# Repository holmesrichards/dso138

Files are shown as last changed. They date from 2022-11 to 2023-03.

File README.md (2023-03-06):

# DSO138 Oscilloscope

This is the JYE Tech DSO138 Oscilloscope put behind a 10 cm wide Kosmo format panel. 

Slide switches, tactile buttons, and trigger indicator LED are mounted to an auxiliary PCB mounted behind the panel. Also on this board are a Eurorack style 10-pin power header with 10 µF caps and power reversal diodes, and a 9 volt regulator and TL072 op amp with associated passive components.

A BNC jack and a 1/4" phone input jack are mounted on the front panel. A toggle switch selects whether the scope input is connected to the BNC or to the 1/4" jack signal after being buffered with the TL072. The latter signal, buffered, also goes to a second 1/4" panel mounted jack, so the signal can be passed on to another module.

Also on the front panel is another toggle switch, controlling the 9 V power. (It's good to power off the scope when not in use, for at least three reasons: the scope draws about 130 mA current on the +12 V rail, it probably puts out some digital noise you don't want getting into your synth sound, and leaving it powered off when not in use will help extend the life of the display.)

Connections to and from each slide switch are sent to the DSO138 switch footprints via an 8-conductor ribbon cable. A fourth ribbon cable connects the tactile buttons, both sides of the LED, and the input signal to the appropriate pads on the main board. Two more wires carry 9 V and ground to that board, which is mounted perpendicular to the front panel. I used a 3D printed carrier and long spacers to attach it.

The display PCB is mounted to the front panel and is connected to the main PCB via a 40 conductor ribbon cable.

## Current draw
130 mA +12 V, 10 mA -12 V

## Photos

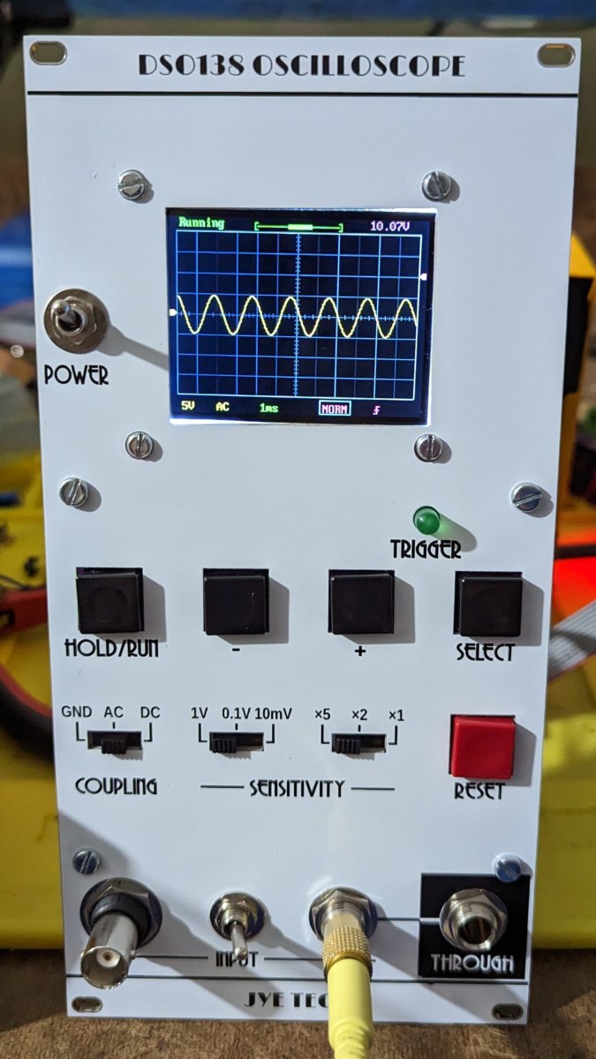
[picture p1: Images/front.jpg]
front


## Documentation

* [Schematic (auxiliary board)](Docs/dso138.pdf)
* PCB layout: [front](Docs/dso138_layout_front.pdf), [back](Docs/dso138_layout_back.pdf)
* [BOM](Docs/dso138_bom.md)
* [Build notes](Docs/build.md)

## GitHub repository

* [https://github.com/holmesrichards/dso138](https://github.com/holmesrichards/dso138)

## Submodules

This repo uses submodules aoKicad and Kosmo_panel, which provide needed libaries for KiCad. To clone:

```
git clone git@github.com:holmesrichards/dso138.git
git submodule init
git submodule update
```

Alternatively do

```
git clone --recurse-submodules git@github.com:holmesrichards/dso138.git
```

Or if you download the repository as a zip file, you must also click on the "aoKicad" and "Kosmo\_panel" links on the GitHub page (they'll be in the Libraries folder and will have "@ something" after them) and download them as separate zip files which you can unzip into this repo's aoKicad and Kosmo\_panel directories (in the Libraries folder).

If desired, copy the files from aoKicad and Kosmo\_panel to wherever you prefer. 

Then in KiCad, go into Edit Symbols and add symbol libraries 

```
aoKicad/AO_symbols
Kosmo_panel/Kosmo
```
and go into Edit Footprints and add footprint libraries 
```
aoKicad/AO_tht
Kosmo_panel/Kosmo_panel.
```

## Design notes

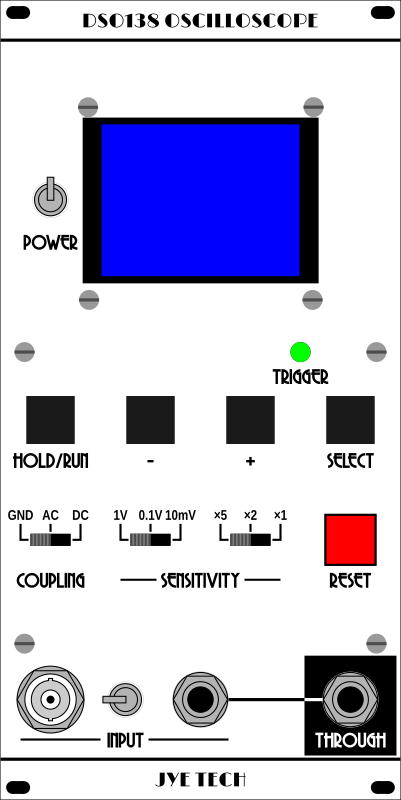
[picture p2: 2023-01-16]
Images/dso138_panel.png

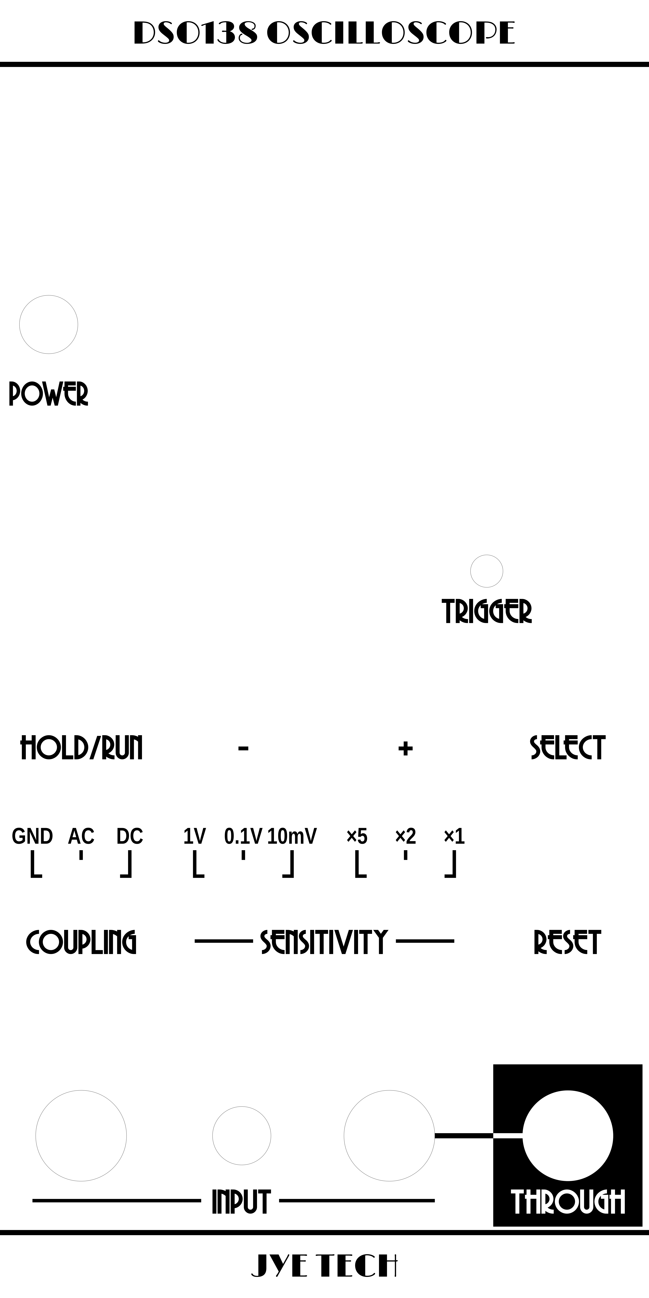
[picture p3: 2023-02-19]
Images/dso138_panel_art.png

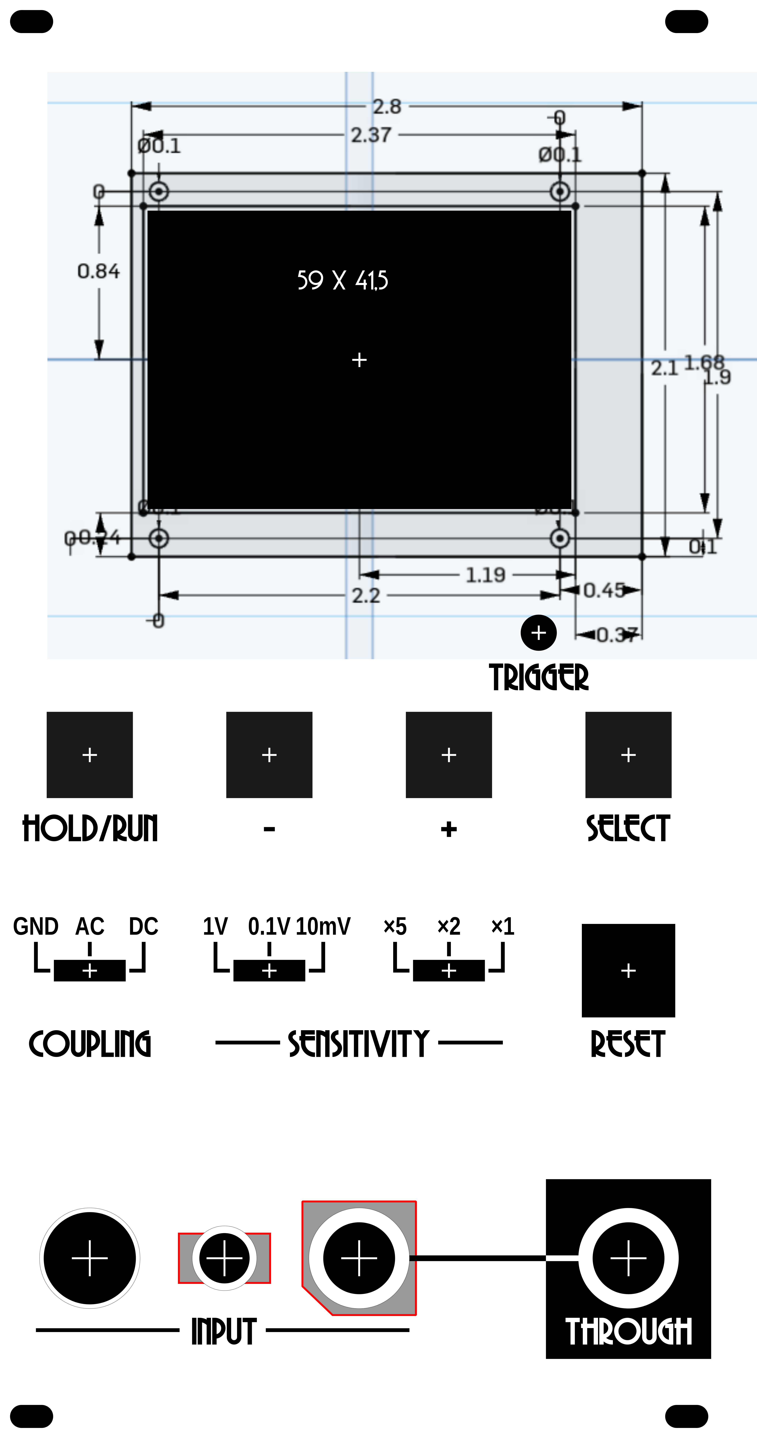
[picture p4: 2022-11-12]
Images/dso138_behind.png

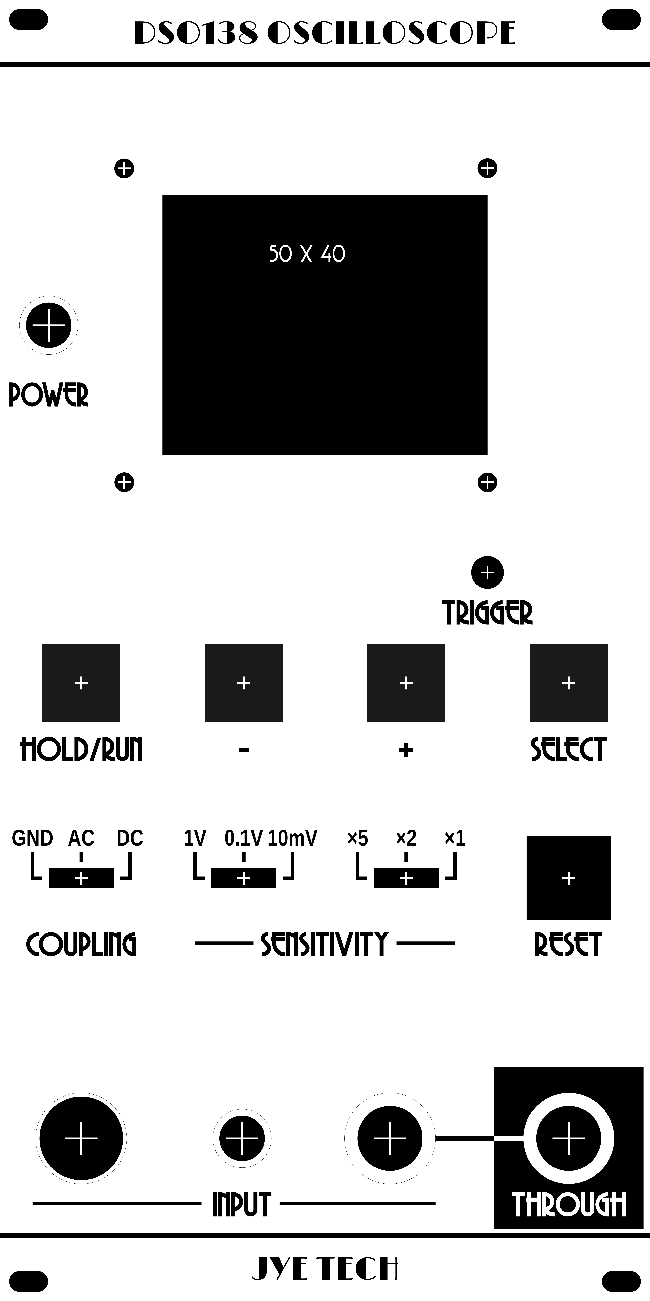
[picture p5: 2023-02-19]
Images/dso138_panel_holes.png

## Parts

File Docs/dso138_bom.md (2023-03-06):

# dso138.kicad_sch BOM

Sun 05 Mar 2023 09:16:09 PM EST

Generated from schematic by Eeschema 7.0.0-da2b9df05c~171~ubuntu22.04.1

**Component Count:** 101

| Refs | Qty | Component | Description | Manufacturer | Part | Vendor | SKU |
| ----- | --- | ---- | --- | ---- | ---- | ---- | ---- |
| C1, C2 | 2 | 10uF | Electrolytic capacitor, 2.5 mm pitch |  |  | Tayda | A-4349 |
| C3, C4, C6 | 3 | 100nF | Ceramic capacitor, 2.5 mm pitch |  |  | Tayda | A-553 |
| C5 | 1 | 330nF | Electrolytic capacitor, 2.5 mm pitch |  |  | Tayda | A-319 |
| D1, D2 | 2 | 1N5817 | Schottky Barrier Rectifier Diode, DO-41 |  |  | Tayda | A-159 |
| D3 | 1 | LED_green | Light emitting diode |  |  | Tayda | A-1553 |
| J1 | 1 | DIP-8 | 8 pin DIP socket |  |  | Tayda | A-001 |
| J2–5, J15 | 5 | Conn_01x02 | Micro JST XH 2.54mm connector with 10 cm wires |  |  | eBay |  |
| J6–9, J14 | 5 | Conn_01x02 | Micro JST XH 2.54mm header |  |  | eBay |  |
| J10–13 | 4 | Conn_02x04_Odd_Even | 2x4 pin shrouded pin header, 2.54 mm pitch |  |  | Tayda | A-2948 |
| J16–19 | 4 | Conn_02x04_Odd_Even | 2x4 pin IDC connector, 2.54 mm pitch |  |  | Tayda | A-3346 |
| J20 | 1 | Synth_power_2x5 | 2x5 pin shrouded pin header, 2.54 mm pitch |  |  | Tayda | A-2939 |
| J21, J22 | 2 | AudioJack2 | Audio Jack, 2 Poles (Mono / TS) |  |  | Tayda | A-1121 |
| J23 | 1 | Conn_Coaxial_BNC | BNC jack, panel mount | Molex | 0731315003 | Digi-Key | WM5379-ND |
| R1, R2 | 2 | 100k | Resistor |  |  | Tayda |  |
| R3, R4 | 2 | 10k | Resistor |  |  | Tayda |  |
| R5 | 1 | 1k | Resistor |  |  | Tayda |  |
| SW1–3 | 3 | SW_DP3T | DP3T slide switch | C&K | OS203012MU5QP1‎ | Digi-Key | CKN9554-ND |
| SW4–8 | 5 | SW_Push | Tactile push button | E-Switch | TL1100F160Q | Digi-Key | EG1821-ND |
| SW9 | 1 | SW_SPST | SPST toggle switch |  |  | Tayda | A-3186 (SPDT, use as SPST) |
| SW10 | 1 | SW_SPDT | SPDT toggle switch |  |  | Tayda | A-3186 |
| U1 | 1 | TL072 | Dual operational amplifier, DIP-8 |  |  | Tayda | A-037 |
| U2 | 1 | LM7809_TO220 | Positive 1A 35V Linear Regulator, Fixed Output 9V, TO-220 |  |  | Tayda | A-1597 |
| W1–4 | 4 | 8 conductor ribbon cable ~ 20 cm | Ribbon cable |  |  | Tayda | A-4935 |
| W5 | 1 | 40 conductor ribbon cable assembly with connectors (1 male, 1 female) | Ribbon cable |  |  | Digi-Key | 1528-4823-ND |
| ZKN1 | 1 | Switch cap | Tactile switch cap, red | E-Switch | 4JRED | Digi-Key | EG1078-ND |
| ZKN2–5 | 4 | Switch cap | Tactile switch cap, black | E-Switch | 4JBLK | Digi-Key | EG1080-ND |
| ZNU1–5 | 5 | M3 nut | nut |  |  |  |  |
| ZNU6–9 | 4 | M2.5 nut | nut |  |  |  |  |
| ZSC1–3, ZSC12–19 | 11 | Μ3 screw 6 mm | screw |  |  |  |  |
| ZSC4–7 | 4 | Μ3 screw 12 mm | screw |  |  |  |  |
| ZSC8–11 | 4 | M2.5 screw 12 mm | screw |  |  |  |  |
| ZSP1–4 | 4 | M3 spacer FF 5 mm | spacer |  |  |  |  |
| ZSP5–8 | 4 | M2.5 spacer FF 5 mm | spacer |  |  |  |  |
| ZSP9–12 | 4 | M3 spacer FF 10 mm | spacer |  |  |  |  |
| ZSP13, ZSP14 | 2 | M3 spacer FF 30 mm | spacer |  |  |  |  |

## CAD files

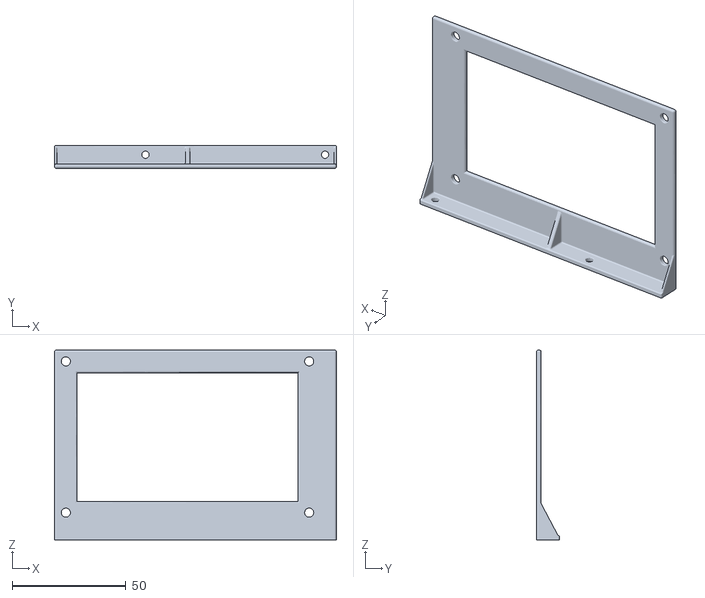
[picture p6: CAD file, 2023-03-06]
3D prints/dso138_bracket.stl
124.0 x 10.0 x 83.5

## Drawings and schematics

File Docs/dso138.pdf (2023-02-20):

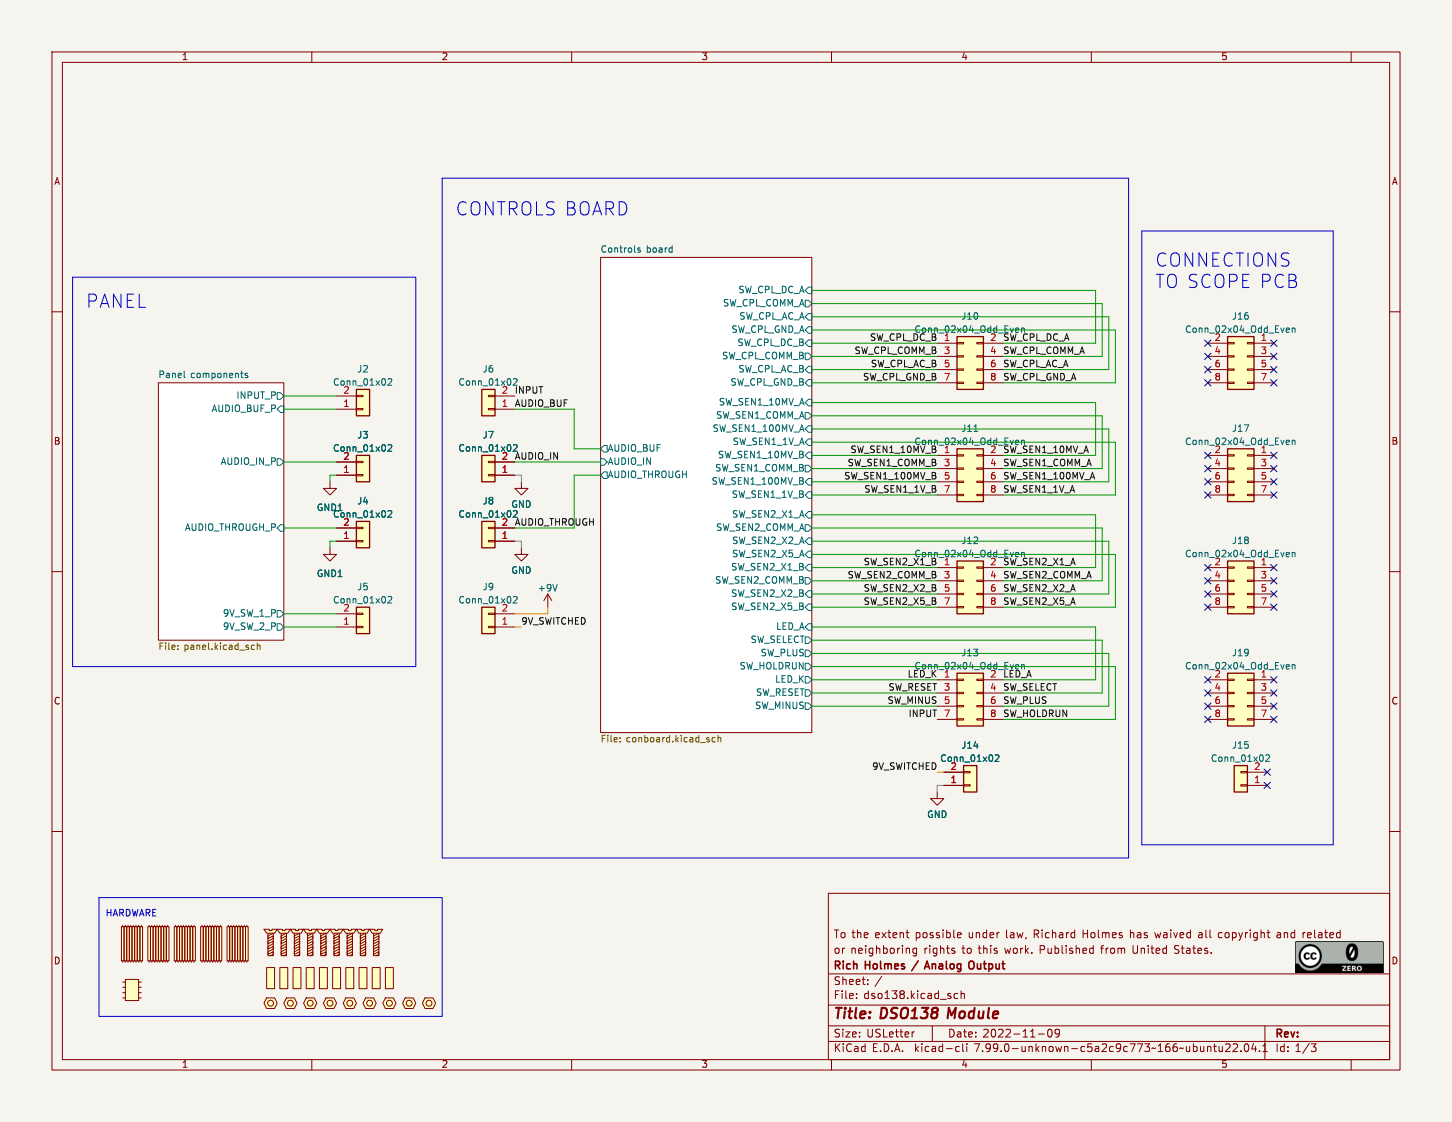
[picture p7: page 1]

SW_MINUS Controls board File: conboard.kicad_sch AUDIO_BUF_P

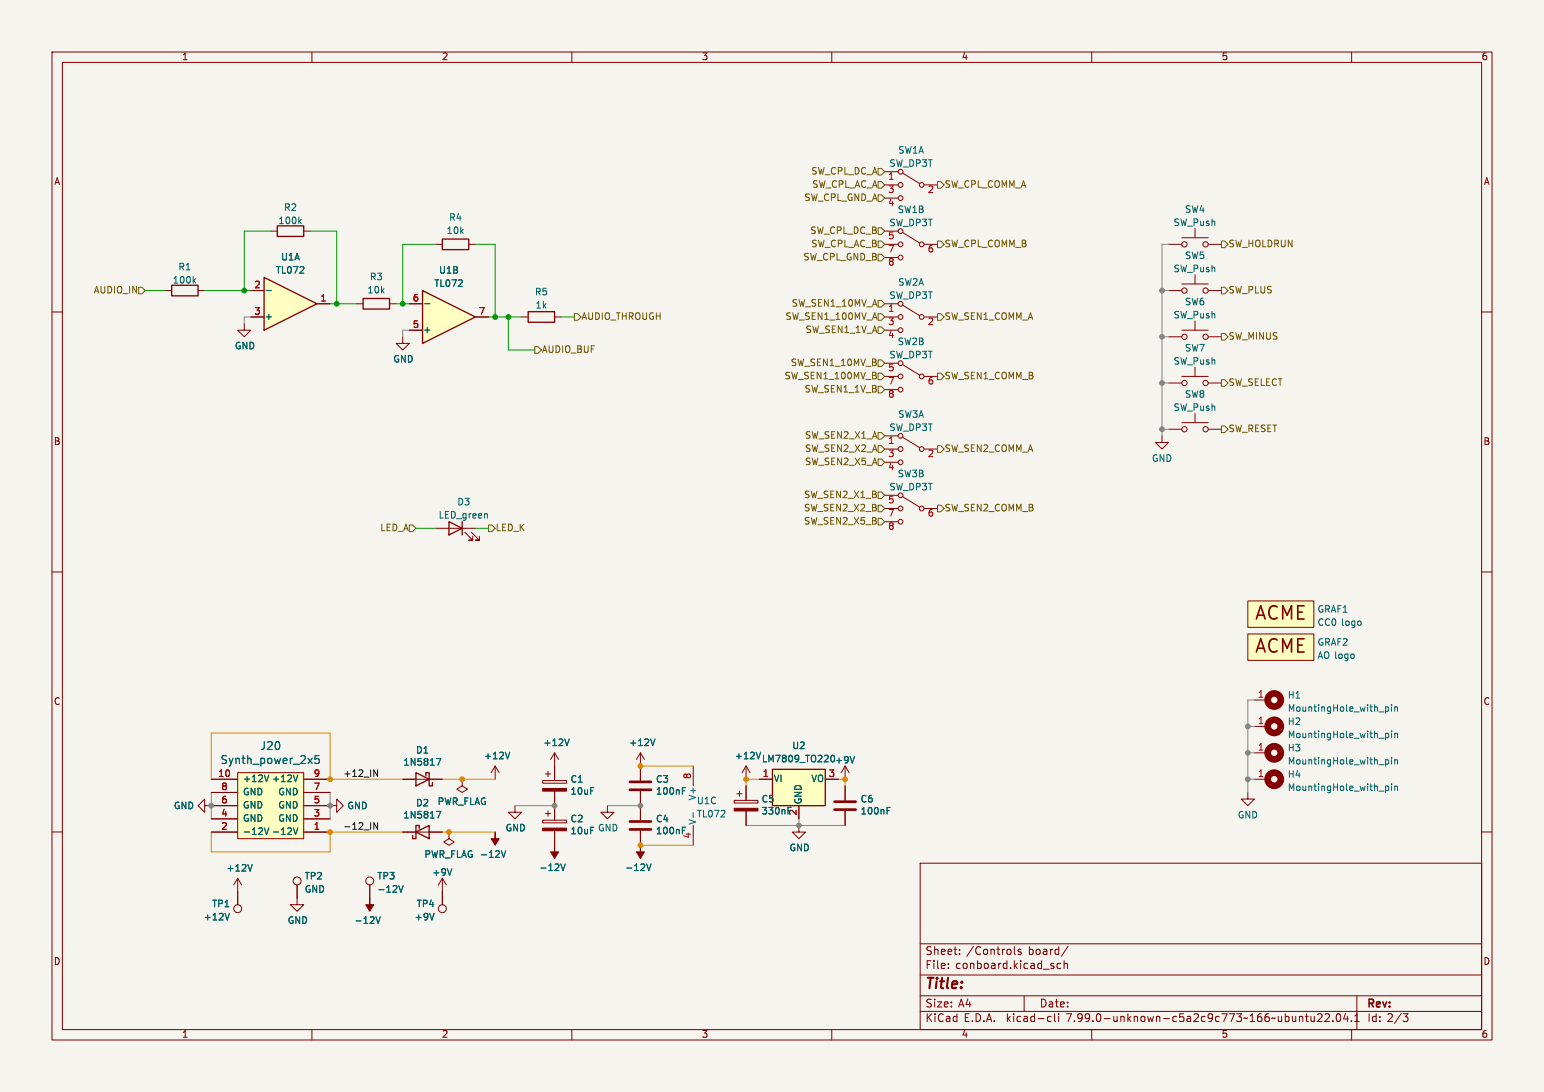
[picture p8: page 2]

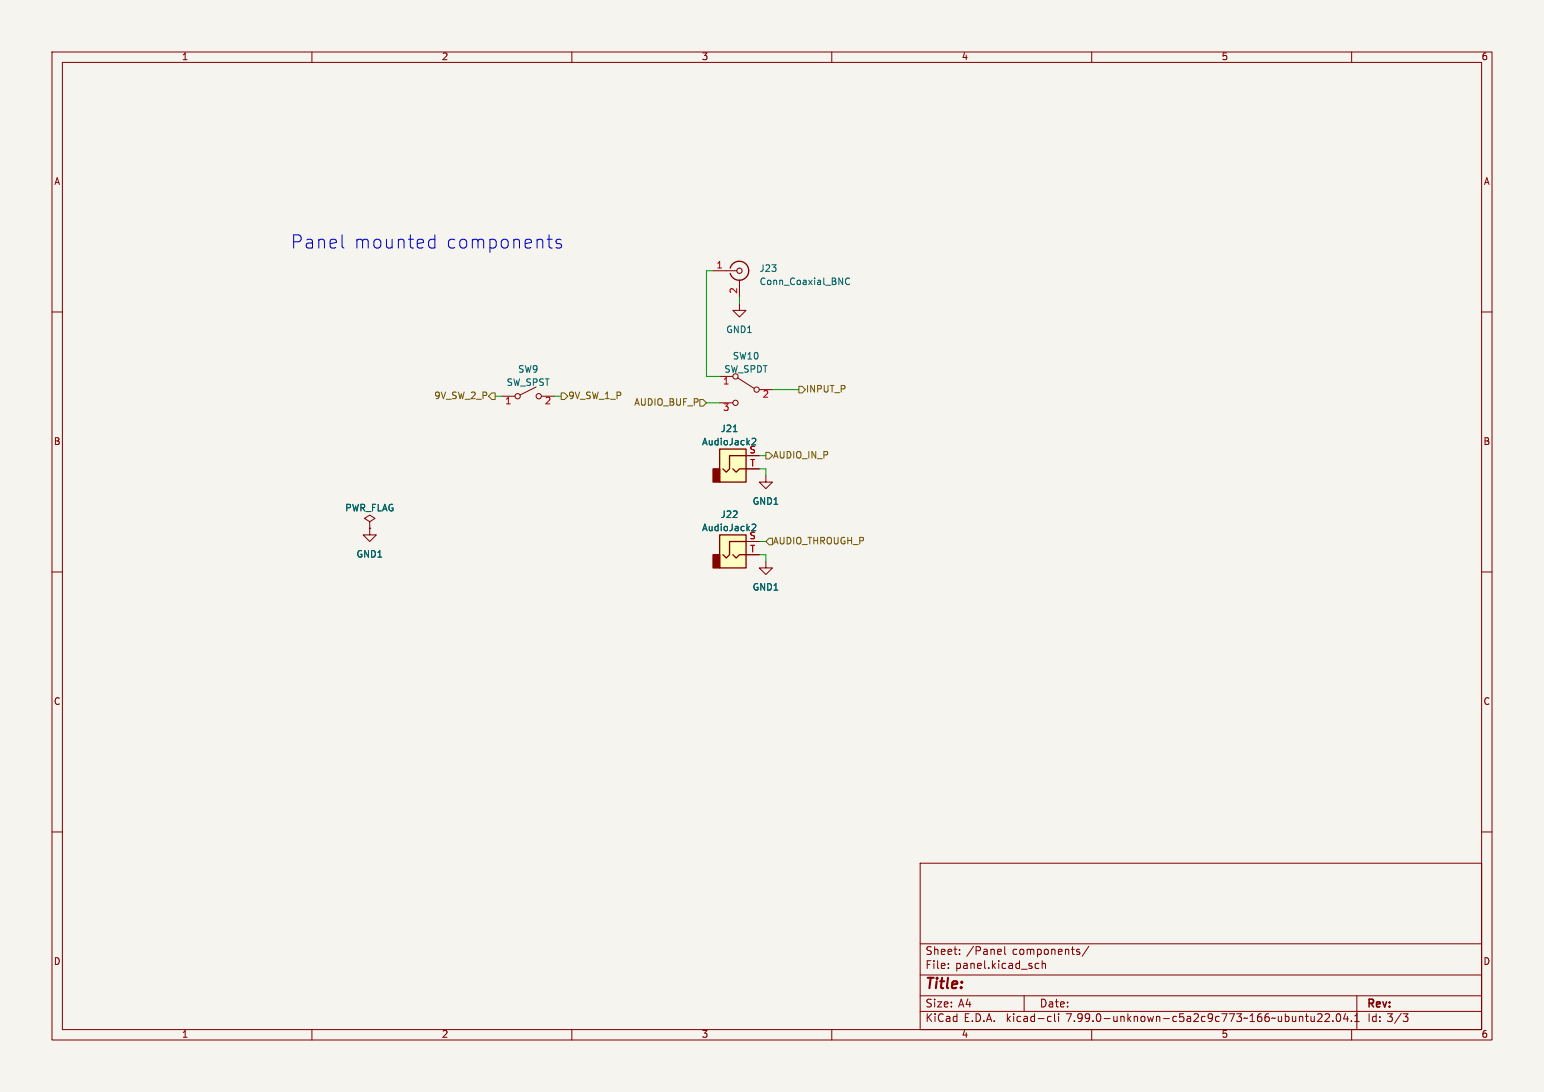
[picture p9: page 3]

Id: 3/3 Title: File: panel.kicad_sch Sheet: /Panel components/

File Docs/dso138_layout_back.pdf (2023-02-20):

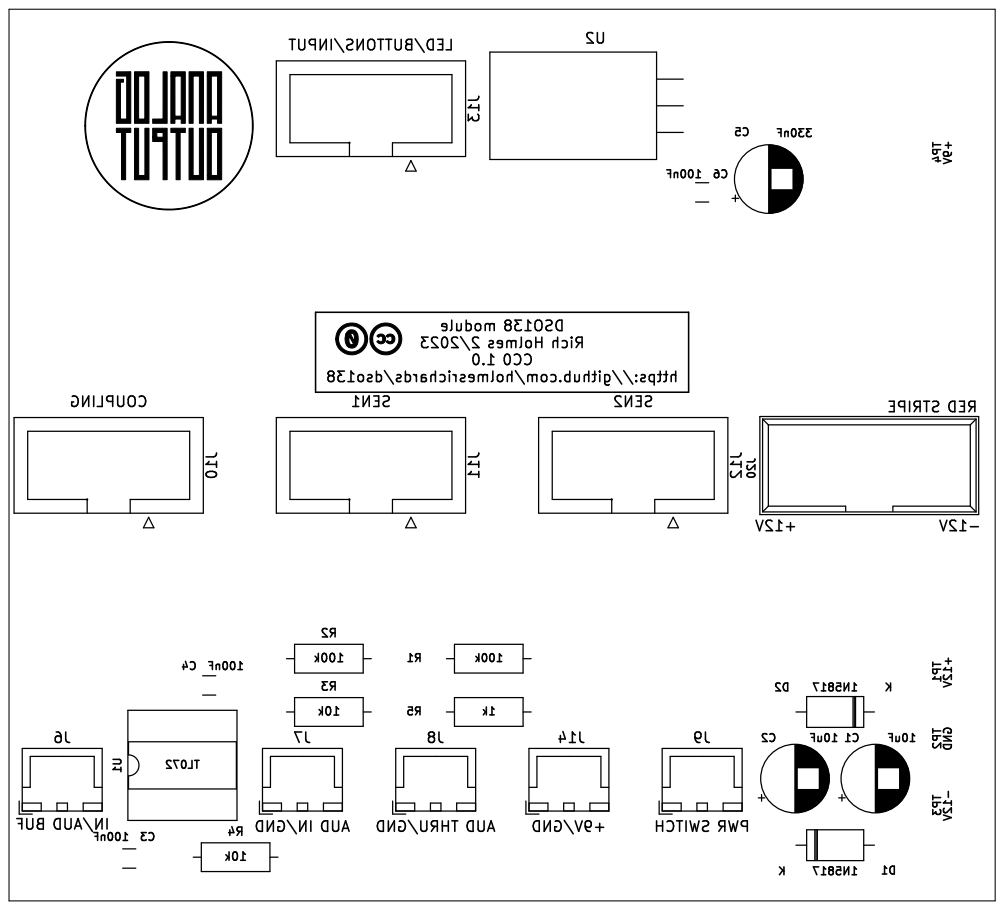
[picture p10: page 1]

LED/BUTTONS/INPUT DSO138 module Rich Holmes 2/2023 CC0 1.0

https://github.com/holmesrichards/dso138 AUD IN/GND TP3 -12V TP4 +9V TP1 +12V TP2 GND J13

COUPLING SEN1 SEN2 AUD THRU/GND +9V/GND

IN/AUD BUF PWR SWITCH

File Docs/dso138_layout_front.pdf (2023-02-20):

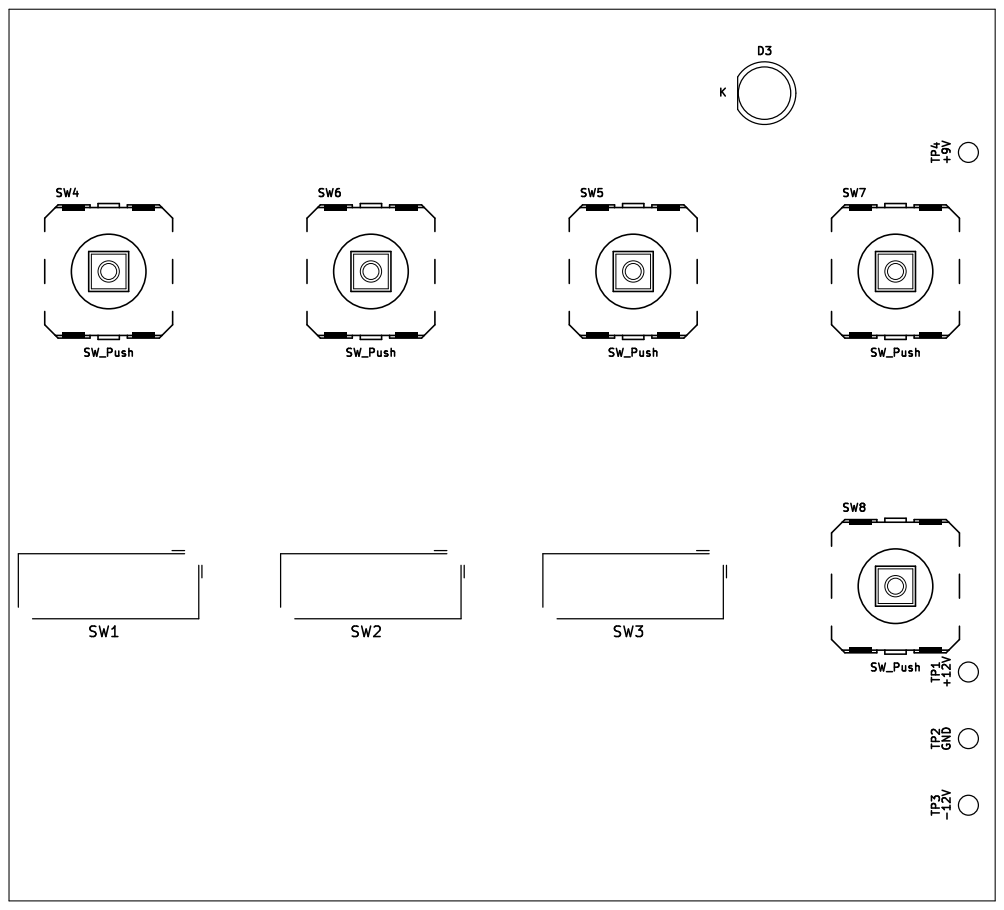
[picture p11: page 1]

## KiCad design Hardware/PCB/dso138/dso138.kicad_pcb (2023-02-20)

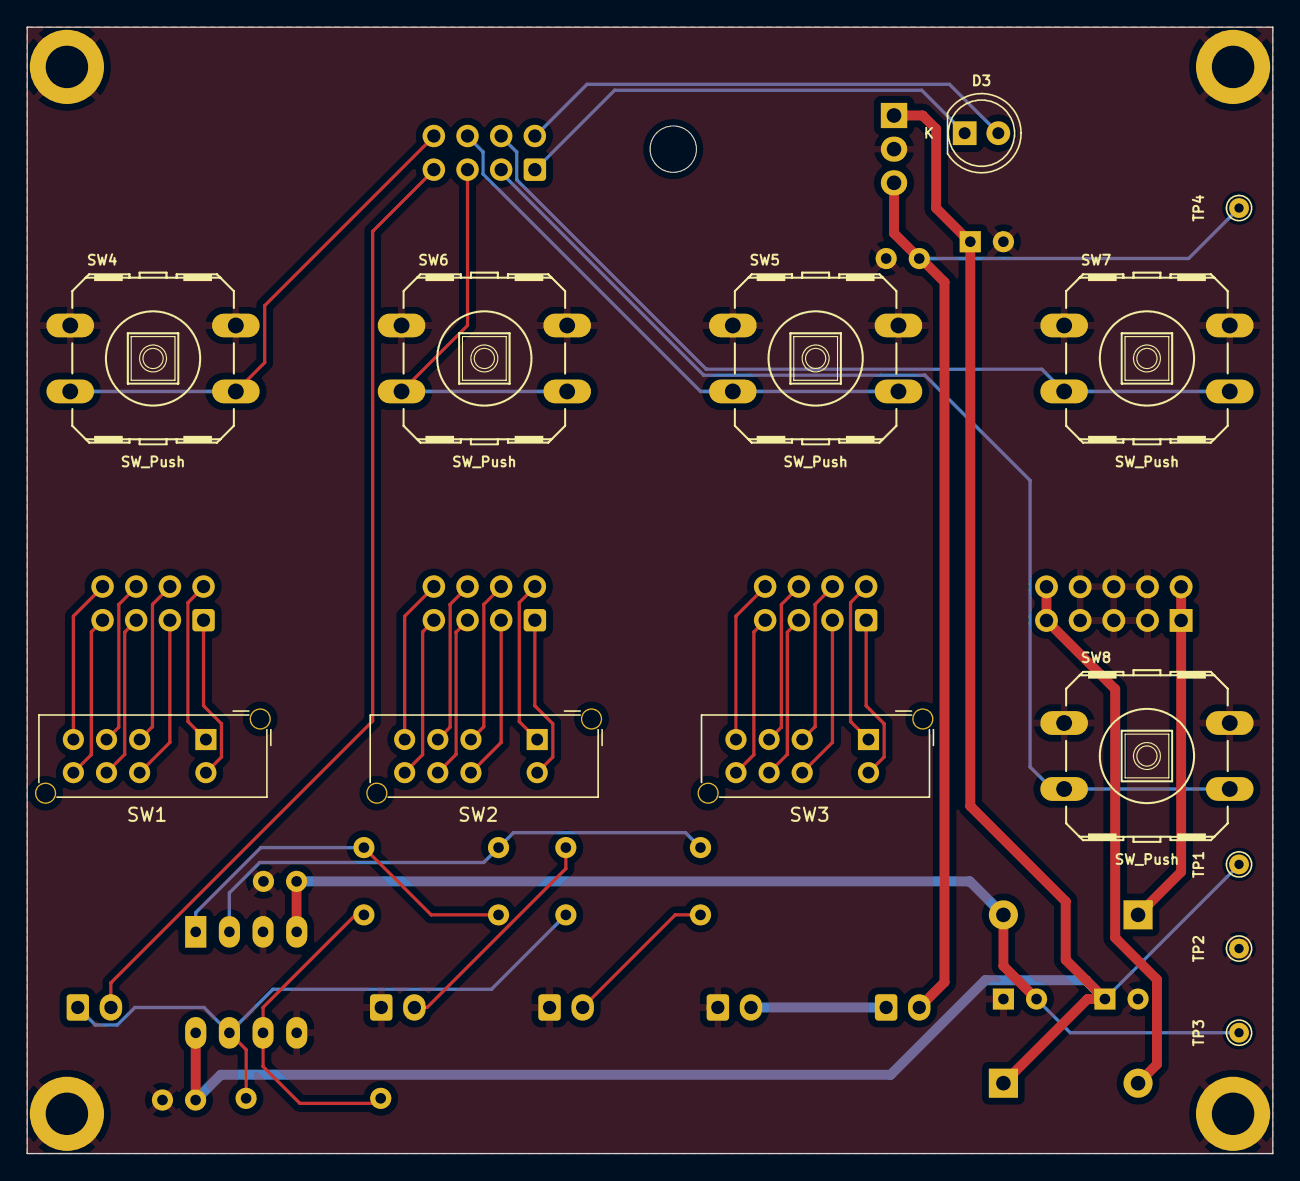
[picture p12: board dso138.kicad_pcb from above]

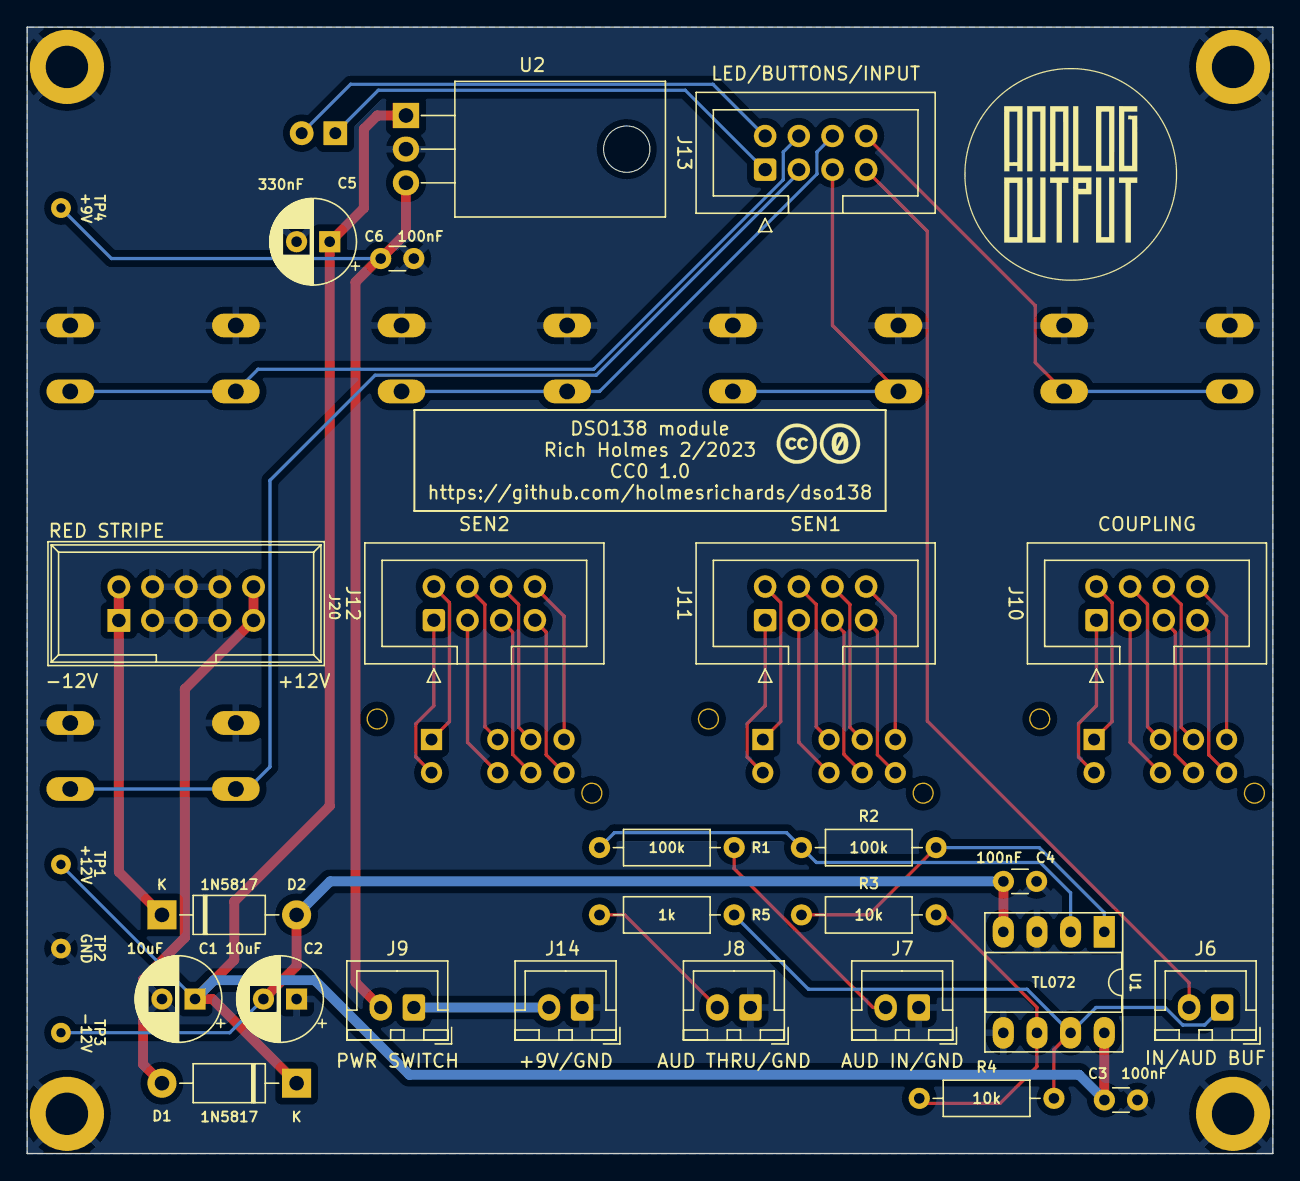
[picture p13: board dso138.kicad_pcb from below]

Board: 2 copper layers, 94.0 x 85.0 mm, 45 parts (27 on the bottom side), 45 nets.

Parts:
C1, C2: 10uF; CP_Radial_D6.3mm_P2.50mm
C3, C4, C6: 100nF; C_Disc_D3.0mm_W1.6mm_P2.50mm
C5: 330nF; CP_Radial_D6.3mm_P2.50mm
D1, D2: 1N5817; D_DO-41_SOD81_P10.16mm_Horizontal
D3: LED_green; LED_D5.0mm
GRAF1: Behind; dso138_behind
GRAF1#2: CC0 logo; CC0_logo
GRAF2: AO logo; analogoutput
H1, H2, H3, H4: MountingHole_with_pin; MountingHole_3.2mm_Pad
J6, J7, J8, J9, J14: Conn_01x02; JST_XH_B2B-XH-A_1x02_P2.50mm_Vertical
J10, J11, J12, J13: Conn_02x04_Odd_Even; IDC-Header_2x04_P2.54mm_Vertical
J20: Synth_power_2x5; Power_Header
R1, R2: 100k; R_Axial_DIN0207_L6.3mm_D2.5mm_P10.16mm_Horizontal
R3, R4: 10k; R_Axial_DIN0207_L6.3mm_D2.5mm_P10.16mm_Horizontal
R5: 1k; R_Axial_DIN0207_L6.3mm_D2.5mm_P10.16mm_Horizontal
SW1, SW2, SW3: SW_DP3T; SW_CK_OS203012MU5QP1_DP3T
SW4, SW5, SW6, SW7, SW8: SW_Push; Tactile_E-switch_TL1100F160Q
TP1: +12V; TestPoint_THTPad_D1.5mm_Drill0.7mm
TP2: GND; TestPoint_THTPad_D1.5mm_Drill0.7mm
TP3: -12V; TestPoint_THTPad_D1.5mm_Drill0.7mm
TP4: +9V; TestPoint_THTPad_D1.5mm_Drill0.7mm
U1: TL072; DIP-8_W7.62mm_Socket_LongPads
U2: LM7809_TO220; TO-220-3_Horizontal_TabDown

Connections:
+9V: C6.1, J9.2, TP4.1, U2.3 (VO)
+12V: C1.1, C3.1, C5.1, D1.1 (K), TP1.1, U1.8 (V+), U2.1 (VI)
-12V: C2.2, C4.2, D2.2 (A), TP3.1, U1.4 (V-)
/9V_SWITCHED: J9.1, J14.2
/AUDIO_BUF: J6.1, R4.2, R5.1, U1.7
/AUDIO_IN: J7.2, R1.1
/AUDIO_THROUGH: J8.2, R5.2
/Controls board/+12_IN: D1.2 (A), J20.9 (+12V), J20.10 (+12V)
/Controls board/-12_IN: D2.1 (K), J20.1 (-12V), J20.2 (-12V)
/INPUT: J6.2, J13.7
/LED_A: D3.2 (A), J13.2
/LED_K: D3.1 (K), J13.1
/SW_CPL_AC_A: J10.6, SW1.3
/SW_CPL_AC_B: J10.5, SW1.7
/SW_CPL_COMM_A: J10.4, SW1.2
/SW_CPL_COMM_B: J10.3, SW1.6
/SW_CPL_DC_A: J10.2, SW1.1
/SW_CPL_DC_B: J10.1, SW1.5
/SW_CPL_GND_A: J10.8, SW1.4
/SW_CPL_GND_B: J10.7, SW1.8
/SW_HOLDRUN: J13.8, SW4.2
/SW_MINUS: J13.5, SW6.2
/SW_PLUS: J13.6, SW5.2
/SW_RESET: J13.3, SW8.2
/SW_SELECT: J13.4, SW7.2
/SW_SEN1_1V_A: J11.8, SW2.4
/SW_SEN1_1V_B: J11.7, SW2.8
/SW_SEN1_10MV_A: J11.2, SW2.1
/SW_SEN1_10MV_B: J11.1, SW2.5
/SW_SEN1_100MV_A: J11.6, SW2.3
/SW_SEN1_100MV_B: J11.5, SW2.7
/SW_SEN1_COMM_A: J11.4, SW2.2
/SW_SEN1_COMM_B: J11.3, SW2.6
/SW_SEN2_COMM_A: J12.4, SW3.2
/SW_SEN2_COMM_B: J12.3, SW3.6
/SW_SEN2_X1_A: J12.2, SW3.1
/SW_SEN2_X1_B: J12.1, SW3.5
/SW_SEN2_X2_A: J12.6, SW3.3
/SW_SEN2_X2_B: J12.5, SW3.7
/SW_SEN2_X5_A: J12.8, SW3.4
/SW_SEN2_X5_B: J12.7, SW3.8
GND: C1.2, C2.1, C3.2, C4.1, C5.2, C6.2, H1.1, H2.1, H3.1, H4.1, J7.1, J8.1, J14.1, J20.3 (GND), J20.4 (GND), J20.5 (GND), J20.6 (GND), J20.7 (GND), J20.8 (GND), SW4.1, SW5.1, SW6.1, SW7.1, SW8.1, TP2.1, U1.3 (+), U1.5 (+), U2.2 (GND)
unnamed: R2.2, R3.1, U1.1
unnamed: R1.2, R2.1, U1.2 (-)
unnamed: R3.2, R4.1, U1.6 (-)

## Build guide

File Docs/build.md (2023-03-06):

# DSO-138 module build notes

The PCB, panel, and mounting fixture in this repo are intended to be used with a DSO-138 scope kit. The kit should be assembled according to its instructions except to omit the following:

* 3 slide switches
* 5 tactile switches
* 1 indicator LED
* 1 BNC jack
* 1 DC barrel jack

Assemble the auxiliary PCB as usual. The regulator can be bent over and screwed to the PCB with a 6 mm M3 screw and nut. Note slide switches and tactile buttons go on the opposite side of the board from everything else. Leave the indicator LED unsoldered in its footprint for now.

Print the mounting fixture from the STL file provided, or use your ingenuity to make something equivalent.

Make four 8-conductor ribbon cables about 15 cm long, enough to reach from the auxiliary PCB to the main PCB (see assembly photos below) with an IDC connector at one end. Orient the connector like you would a Eurorack power cable so the red stripe corresponds to conductor 1, then the remaining conductors are 2 through 8. Separate the conductors and strip insulation at the other end. The conductors are soldered to the main PCB as follows:

3 cables are soldered to the slide switch footprints as shown:

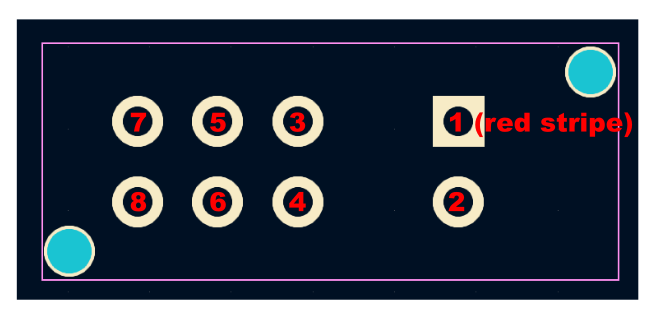
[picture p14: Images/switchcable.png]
switchcable


The fourth cable's conductors go to various footprints:

* 1 to LED cathode
* 2 to LED anode (marked +)
* 3 to SW8 button (RESET), top left pad (closest to LED)
* 4 to SW7 button (SEL), bottom left pad
* 5 to SW6 button (-), bottom left pad
* 6 to SW5 button (+), bottom left pad
* 7 to input pad (either AIN or adjacent one on PNC footprint)
* 8 to SW4 button (OK), bottom left pad

Take a pair of wires with a micro JST XH2.54 connector on one end and solder the other ends to the DC power +9 V and Ground footprints on the main PCB. Take care with which wire goes to which point. The one that is on the right when plugged into the JST header on the auxiliary PCB should connect to ground.

The display LED PCB is connected to the main PCB using a 40 position ribbon cable with male IDC connector on one end and female on the other. Pay attention to the orientation; each pin should connect to the socket position it would have connected to if you had plugged the display board directly into the main one.

Assemble the module as follows:

Put 12 mm M3 screws in the holes in the lower half of the front panel. Put 5 mm M3 spacers on these screws behind the panel. Mount the auxiliary PCB on the screws with the JST headers at the bottom. Secure with two M3 nuts on the left side (viewed from behind the panel) and two 30 mm M3 spacers on the right. Make sure the LED is positioned in its hole, then solder it.

Put 12 mm M2.5 screws in the holes in the upper half of the front panel. Put 5 mm M2.5 spacers on these screws behind the panel. Mount the display PCB on the screws with the 40 pin header on the left side. Secure with four M2.5 nuts.

Attach the main PCB to the 3D printed fixture (or whatever equivalent you are using) with 6 mm M3 screws and 10 mm M3 spacers. Attach the fixture to the 30 mm spacers with 6 mm M3 screws. The (intended, as indicated by the silkscreen) top of the PCB should be toward the panel; the 40 pin socket should be near the (actual) top.

Plug the ribbon cables into the shrouded headers; refer to the silkscreen to determine which goes where.

Plug the JST connector connected to the power footprint into the header marked +9V/GND. Verify the wire on the right goes to ground on the main PCB.

Install jacks and toggle switches on the panel. The power toggle (next to the LED display) is mounted vertically and the input toggle is mounted horizontally.

Solder 4 more pairs of wires with JST connectors and plug them in as follows:

* Solder to center and bottom terminals of the power switch. These can go either way around. Plug in to header marked PWR SWITCH.
* Solder to signal and ground terminals of the THROUGH 1/4" jack. Plug in to header marked AUD THRU/GND. Ground must go to the header pin on the right.
* Solder to signal and ground terminals of the INPUT 1/4" jack. Plug in to header marked AUD IN/GND. Ground must go to the header pin on the right.
* Solder to center and right terminals of the INPUT switch. Plug in to header marked IN/AUD BUF. Right terminal must go to the header pin on the right.

Wire the center pin of the BNC jack to the left terminal of the INPUT switch. Wire the ground pin of the BNC jack to the ground pin of the INPUT 1/4" jack.

You're done! Assuming it works.

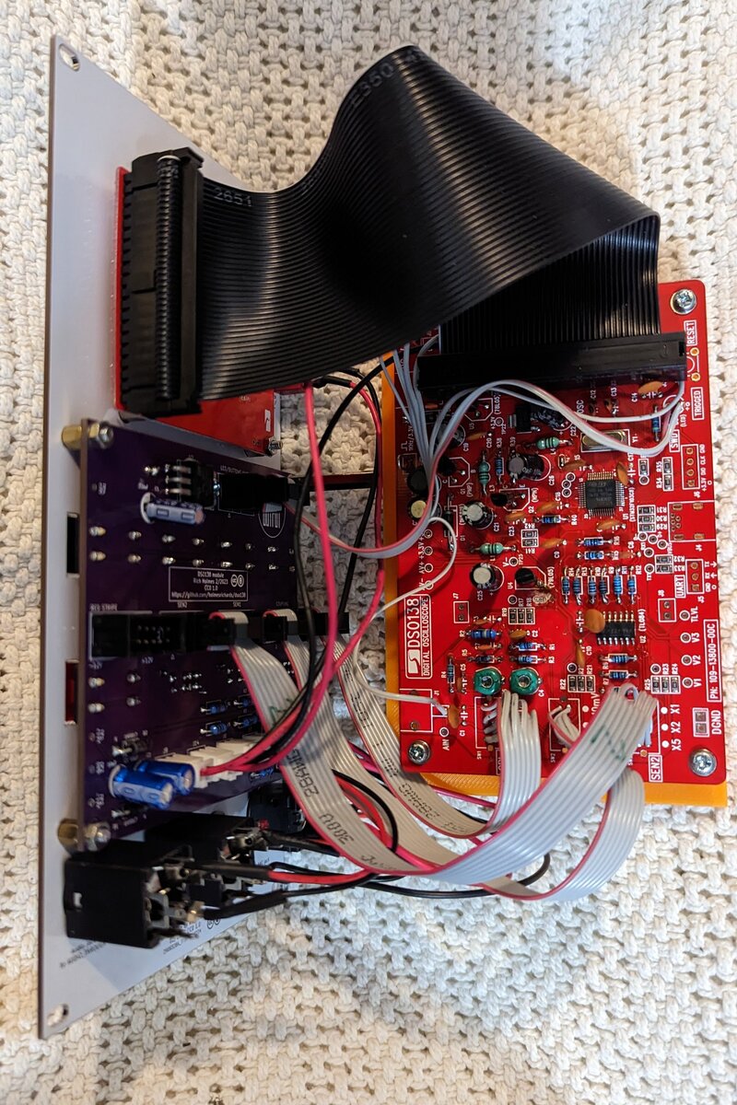
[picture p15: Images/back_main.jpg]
back_main
 

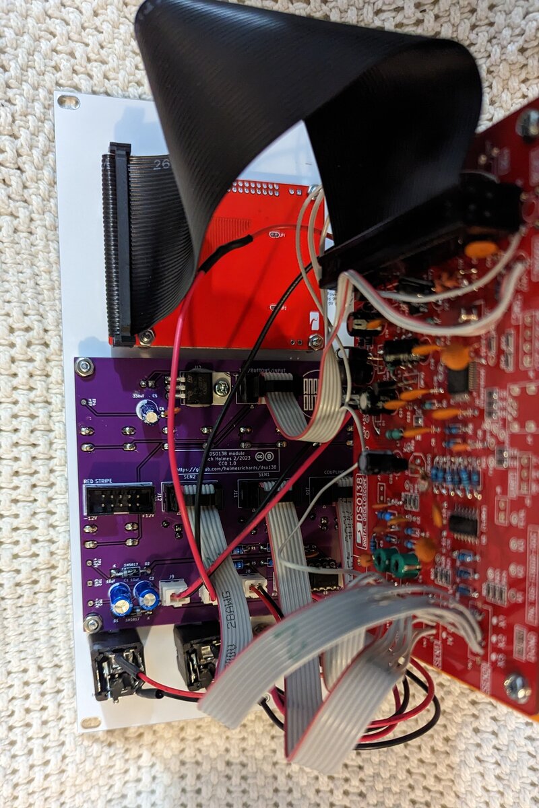
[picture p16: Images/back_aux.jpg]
back_main
 

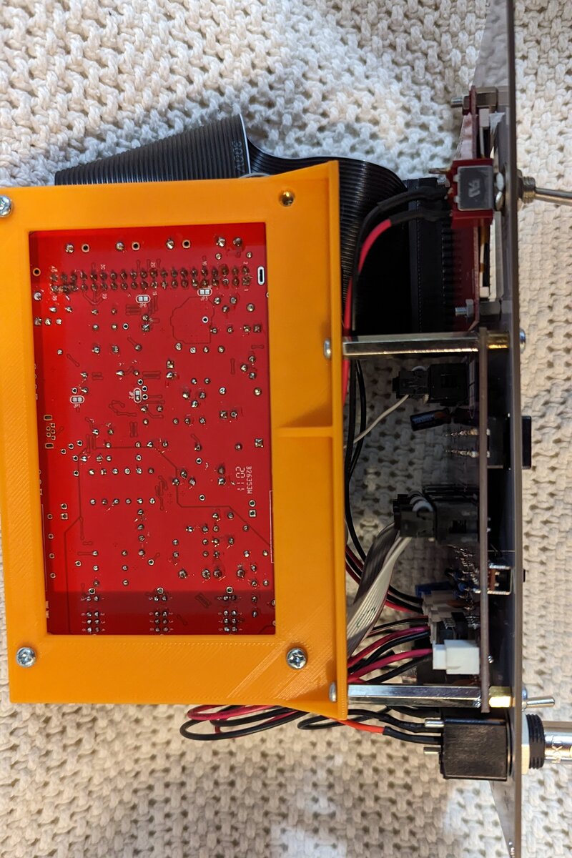
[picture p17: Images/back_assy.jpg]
back_main


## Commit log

2022-11-12 Initial version
    [dso138-CmtUser.gbr, dso138-CuBottom.gbl, dso138-CuTop.gtl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]
2022-11-27 Add power switch
2023-02-05 KiCad 7; Reorg schematic and add panel components & connectors; re-enable 3D models
    [conboard.kicad_sch, dso138.kicad_pcb, dso138.kicad_sch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]
2023-02-19 TO-220 regulator; panel
    [conboard.kicad_sch, dso138.kicad_pcb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]
2023-02-20 Net classes, move 7809 and make horizontal, inverting buffers, power switch via PCB
    [conboard.kicad_sch, dso138.kicad_pcb, dso138.kicad_sch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]
2023-03-06 STL file; BOM; documentation
    [conboard.kicad_sch, dso138.kicad_sch, dso138_bracket.stl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]
2023-03-06 BOM correction
    [conboard.kicad_sch]

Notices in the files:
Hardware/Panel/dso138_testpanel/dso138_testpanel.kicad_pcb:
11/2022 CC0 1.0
